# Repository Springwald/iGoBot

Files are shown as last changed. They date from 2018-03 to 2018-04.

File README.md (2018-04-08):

iGoBot - a GO game playing robot

	 _ _____      ______       _   
	(_)  __ \     | ___ \     | |  
	 _| |  \/ ___ | |_/ / ___ | |_ 
	| | | __ / _ \| ___ \/ _ \| __|
	| | |_\ \ (_) | |_/ / (_) | |_ 
	|_|\____/\___/\____/ \___/ \__|
                               
Project website: [http://www.springwald.de/hi/igobot](http://www.springwald.de/hi/igobot)



Licensed under MIT License (MIT)

Copyright (c) 2018 Daniel Springwald | daniel@springwald.de

Permission is hereby granted, free of charge, to any person obtaining a copy of this software and associated documentation files (the "Software"), to deal in the Software without restriction, including without limitation the rights to use, copy, modify, merge, publish, distribute, sublicense, and/or sell copies of the Software, and to permit persons to whom the Software is furnished to do so, subject to the following conditions:

The above copyright notice and this permission notice shall be included in all copies or substantial portions of the Software.

THE SOFTWARE IS PROVIDED "AS IS", WITHOUT WARRANTY OF ANY KIND, EXPRESS OR IMPLIED, INCLUDING BUT NOT LIMITED TO THE WARRANTIES OF MERCHANTABILITY, FITNESS FOR A PARTICULAR PURPOSE AND NONINFRINGEMENT. IN NO EVENT SHALL THE AUTHORS OR COPYRIGHT HOLDERS BE LIABLE FOR ANY CLAIM, DAMAGES OR OTHER LIABILITY, WHETHER IN AN ACTION OF CONTRACT, TORT OR OTHERWISE, ARISING FROM, OUT OF OR IN CONNECTION WITH THE SOFTWARE OR THE USE OR OTHER DEALINGS IN THE SOFTWARE.

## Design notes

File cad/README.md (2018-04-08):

iGoBot - a GO game playing robot

	 _ _____      ______       _   
	(_)  __ \     | ___ \     | |  
	 _| |  \/ ___ | |_/ / ___ | |_ 
	| | | __ / _ \| ___ \/ _ \| __|
	| | |_\ \ (_) | |_/ / (_) | |_ 
	|_|\____/\___/\____/ \___/ \__|
                               
Project website: [http://www.springwald.de/hi/igobot](http://www.springwald.de/hi/igobot)

## CAD Files

### The stone dispenser

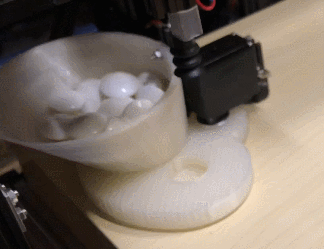
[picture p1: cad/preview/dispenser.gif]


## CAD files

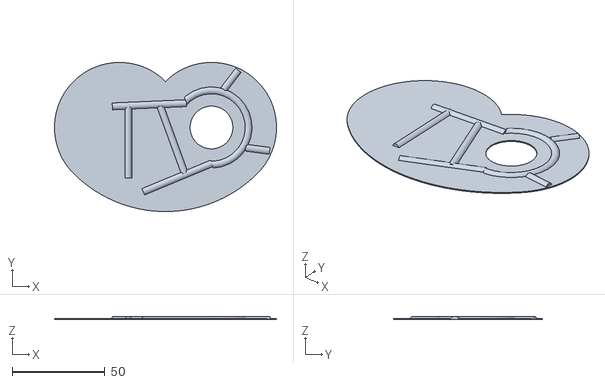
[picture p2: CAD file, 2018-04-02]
cad/StoneDispenserStoneBumper.stl
119.5 x 80.2 x 1.74

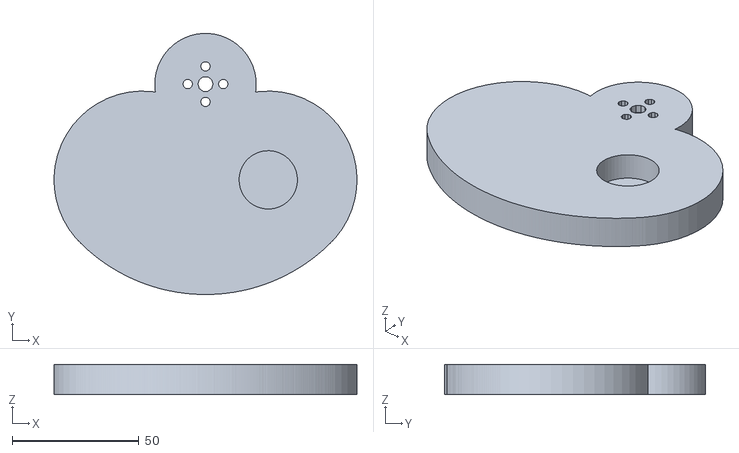
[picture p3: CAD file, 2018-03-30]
cad/StoneDispenserPlate.stl
119.5 x 102.9 x 12.0

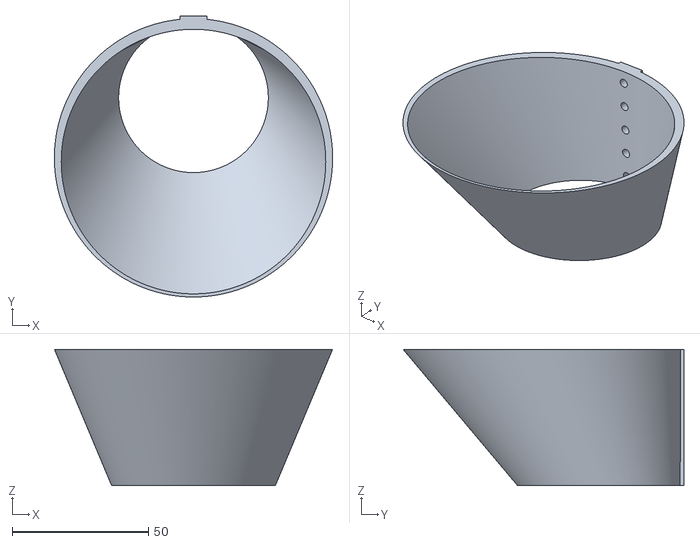
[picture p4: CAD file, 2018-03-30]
cad/StoneDispenserStorage.stl
102.0 x 103.0 x 50.0

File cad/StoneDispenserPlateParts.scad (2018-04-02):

/*
iGoBot - a GO game playing robot
	 _ _____      ______       _   
	(_)  __ \     | ___ \     | |  
	 _| |  \/ ___ | |_/ / ___ | |_ 
	| | | __ / _ \| ___ \/ _ \| __|
	| | |_\ \ (_) | |_/ / (_) | |_ 
	|_|\____/\___/\____/ \___/ \__|
                               
Project website:
http://www.springwald.de/hi/igobot

 #########################
 # stone dispenser plate #
 #########################

 Licensed under MIT License (MIT)

 Copyright (c) 2018 Daniel Springwald | daniel@springwald.de

 Permission is hereby granted, free of charge, to any person obtaining
 a copy of this software and associated documentation files (the
 "Software"), to deal in the Software without restriction, including
 without limitation the rights to use, copy, modify, merge, publish,
 distribute, sublicense, and/or sell copies of the Software, and to permit
 persons to whom the Software is furnished to do so, subject to
 the following conditions:

 The above copyright notice and this permission notice shall be
 included in all copies or substantial portions of the Software.

 THE SOFTWARE IS PROVIDED "AS IS", WITHOUT WARRANTY OF ANY KIND, EXPRESS
 OR IMPLIED, INCLUDING BUT NOT LIMITED TO THE WARRANTIES OF MERCHANTABILITY,
 FITNESS FOR A PARTICULAR PURPOSE AND NONINFRINGEMENT. IN NO EVENT SHALL
 THE AUTHORS OR COPYRIGHT HOLDERS BE LIABLE FOR ANY CLAIM, DAMAGES OR OTHER
 LIABILITY, WHETHER IN AN ACTION OF CONTRACT, TORT OR OTHERWISE, ARISING
 FROM, OUT OF OR IN CONNECTION WITH THE SOFTWARE OR THE USE OR OTHER
 DEALINGS IN THE SOFTWARE.

*/

function resolutionLow() = ($exportQuality==true) ? 30 : 10;
function resolutionHi() = ($exportQuality==true) ? 300 : 50;

storageHeight = 50;
plateWidth= 70;
plateHeight = 12;
storageWidth = plateWidth-10;
servoMove = 13;

module ServoAxisDisc(holeRadiusPlus) {
    discHeight = 2;
    discRadius = 10;
    //translate([0, 0, discHeight/2]) cylinder(h=discHeight, r=discRadius, $fn=resolutionLow(), center=true); 
    
    mountingHoleSpacing = 14.0/2;
    holeHeight=60;
    holeRadius = 1.9+holeRadiusPlus;
    translate([+mountingHoleSpacing,0, 2+holeHeight/2]) cylinder(h=holeHeight, r=holeRadius, $fn=resolutionLow(), center=true); 
    translate([-mountingHoleSpacing,0, 2+holeHeight/2]) cylinder(h=holeHeight, r=holeRadius, $fn=resolutionLow(), center=true); 
    translate([0,+mountingHoleSpacing, 2+holeHeight/2]) cylinder(h=holeHeight, r=holeRadius, $fn=resolutionLow(), center=true); 
    translate([0,-mountingHoleSpacing, 2+holeHeight/2]) cylinder(h=holeHeight, r=holeRadius, $fn=resolutionLow(), center=true); 
    
    // Screw hole middle
    translate([0,0, 2+holeHeight/2])  cylinder(h=holeHeight, r=3+holeRadiusPlus, $fn=resolutionLow(), center=true); 
}

module GoStone() {
    height = 10;
    diameter = 23;
    color([1,0,0]) {
        cylinder(h=height, r=diameter/2, $fn=resolutionHi(), center=true); 
        //cylinder(h=height*10, r=diameter/3, $fn=resolutionHi(), center=true); 
    }
}

module MakerBeamHoles() {
    height  = 40;
    radius = 3.3;
    for(y = [0 : 10: height]) {
        translate([0,30,y+5]) {
            rotate( [0,90,90]) 
            {
                cylinder(h=30, r=radius/2, $fn=resolutionLow(), center=true); // base body corner
            }
        }
    }
}

module StorageShape(height, radius, widthAddScale, margin) {
    linear_extrude(height, center = true, convexity = 100, scale=widthAddScale + margin/radius) 
        translate([0, -radius-margin, 0])
            circle(r=radius, $fn=resolutionHi());
}

module Storage3() {
    widthAddScale = 1.7;
    margin = 3;
    difference() 
    {
        color([0.7,0.7,1]) 
        {
         translate([0, storageWidth/2 , storageHeight / 2]) 
            difference() {
                StorageShape(storageHeight, storageWidth/2, widthAddScale, 0);
                radiusMinusElement = (storageWidth-margin*2)/2;
                translate([0, margin/2 ,0]) 
                    StorageShape(storageHeight+2,radiusMinusElement , widthAddScale , margin);
            }
         translate([0,storageWidth/2,storageHeight/2]) cube([10,2,storageHeight], center=true);
        }
     MakerBeamHoles();
    }
}

module PlateRaw(height){
    difference() 
    {
        union()
        {
            for (i = [-45:45]) {
                rotate([0,0,i]) {
                    translate([0,-plateWidth/2,-plateHeight/2]) cylinder(h=height, r=plateWidth/2, $fn=resolutionHi(), center=true); 
                }
            }
        }
        union() {
           rotate([0,0,45]) {
            translate([0,-plateWidth/2,-4.9])  GoStone();
           }
        }
    }
}

module PlateStoneBumper() {
    height = 0.5;
    bumperHeight = 2;
    
    
    difference()  {
        
        union() {
        
            translate([0,0,-0.5]) PlateRaw(height);
            
            // ring
            difference() {
                rotate([0,0,45]) 
                    translate([0,-plateWidth/2,-15-bumperHeight]) 
                        rotate_extrude(convexity = 10,  $fn=resolutionLow())
                            translate([20, 10, 0])
                                circle(r = bumperHeight,  $fn=resolutionLow());
                translate([0,-plateWidth/3,0]) 
                    rotate([0,0,45/2]) 
                        cube([30,100,30], center=true);
            }
            
            //line1+2
            translate([0,-plateWidth/2-1,-5-bumperHeight]) 
                rotate([0,0,45/2]) {
                    translate([1,25,0])
                        rotate([90,0,70]) 
                            cylinder(h=40, r=bumperHeight, $fn=resolutionLow(), center=true); 
                    translate([0,-17,0])
                        rotate([90,0,90]) 
                            cylinder(h=40, r=bumperHeight, $fn=resolutionLow(), center=true); 
                }
           
            // line 3
            translate([4,-12,-5-bumperHeight]) 
                translate([0,-20,0])
                    rotate([90,0,20]) 
                        cylinder(h=40, r=bumperHeight, $fn=resolutionLow(), center=true); 
            
            //line4+5
            translate([42,-18,-5-bumperHeight]) 
                rotate([0,0,45/2]) {
                    translate([1,20,0])
                        rotate([90,0,120]) 
                            cylinder(h=13, r=bumperHeight, $fn=resolutionLow(), center=true); 
                    translate([0,-20,0])
                        rotate([90,0,60]) 
                            cylinder(h=13, r=bumperHeight, $fn=resolutionLow(), center=true); 
                }
                
            // line 6
            translate([-20,-12,-5-bumperHeight]) 
                translate([0,-20,0])
                    rotate([90,0,0]) 
                        cylinder(h=40, r=bumperHeight, $fn=resolutionLow(), center=true); 
        }
        translate([0,0,-16.75]) cube([400,400,20],center=true);
    }
}

module Plate(rotation) {
    
    // The servo holder
    difference() 
    {
        translate([0,servoMove,-plateHeight/2]) 
        {
            cylinder(h=plateHeight, r=20, $fn=resolutionHi(), center=true); 
        }
        union() {
            rotate([0,180,0]) translate([0,servoMove,-10]) ServoAxisDisc(holeRadiusPlus=0);
            rotate([0,0,0]) translate([0,servoMove,-65]) ServoAxisDisc(holeRadiusPlus=3);
        }
    }

    // The plate
    PlateRaw(plateHeight);

    
}



//$exportQuality = false;
color([0,1,0]) cylinder(h=200, r=1, $fn=resolutionLow(), center=true); 

//translate([0,0,1]) Storage3(); 


translate([0,plateWidth/2,0]) {
    rotate([0,0,0]) {
        //Plate();
    }
}

PlateStoneBumper();

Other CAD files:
cad/StoneDispenserPlate.scad
cad/StoneDispenserStoneBumper.scad
cad/StoneDispenserStorage.scad

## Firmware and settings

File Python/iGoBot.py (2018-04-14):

#!/usr/bin/python
#-*-coding:utf-8-*-
#vim: set enc=utf8:

#     iGoBot - a GO game playing robot
#      _ _____      ______       _   
#     (_)  __ \     | ___ \     | |  
#      _| |  \/ ___ | |_/ / ___ | |_ 
#     | | | __ / _ \| ___ \/ _ \| __|
#     | | |_\ \ (_) | |_/ / (_) | |_ 
#     |_|\____/\___/\____/ \___/ \__|
#                              
#     Project website: http://www.springwald.de/hi/igobot
#
#     Licensed under MIT License (MIT)
#
#     Copyright (c) 2018 Daniel Springwald | daniel@springwald.de
#
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
import os, sys
from os.path import abspath

import time
from random import randrange, uniform
import math
import pygame
import grovepi
import random

from Board import Board
from GnuGoRemote import GnuGoRemote
from CameraStoneDetection import CameraStoneDetection
from BoardDetectionCalibration import BoardDetectionCalibration
from DanielsRasPiPythonLibs.speech.SpeechOutput import SpeechOutput

from DanielsRasPiPythonLibs.hardware.PCF8574 import PCF8574
from DanielsRasPiPythonLibs.hardware.I2cIoExpanderPcf8574Synchron import I2cIoExpanderPcf8574Synchron
from DanielsRasPiPythonLibs.hardware.RgbLeds import RgbLeds
from hardware.Light import Light
from hardware.Motors import Motors
from hardware.iGoBotRgbLeds import iGoBotRgbLeds

import atexit
import gettext

englishSpeech = False

if (englishSpeech == True):
	en = gettext.translation('iGoBot', localedir='locale', languages=['en'])
	en.install
	_ = en.gettext
else:
	_ = lambda s: s

class iGoBot:

	englishSpeech 					= True;

	I2cIoExpanderPcf8574Adress		= 0x3e

	_lightGrovePort					= 8
	_soundcard						="plughw:1"
	
	_ended							= False
	_released						= False
	
	_motors							= None;
	_light							= None;
	_leds							= None;
	_speech							= None;
	_board							= None;
	_switches 						= None;
	
	_gnuGo							= None;
	
	_camera							= None;
	_cameraStoneDetection			= None;
	
	
	def __init__(self, boardSize=13):
		#pygame.init()
		#pygame.mixer.quit() # to prevent conflicts with speech output (audio device busy)
		#screenInfo = pygame.display.Info()
		#if (screenInfo.current_w > 900):
		#self.lcd = pygame.display.set_mode((800,480))
		#else:
		#	self.lcd = pygame.display.set_mode((800,480), FULLSCREEN, 16)
		
		self._light = Light(self._lightGrovePort);
		self._light.On();
		
		self._leds = iGoBotRgbLeds();
		
		if (englishSpeech==True):
			self._speech = SpeechOutput(soundcard=self._soundcard, voice="-ven");
		else:
			self._speech = SpeechOutput(soundcard=self._soundcard, voice="-vmb-de2");
			
		
		
		self._board = Board(boardSize);
		
		self._switches = I2cIoExpanderPcf8574Synchron(self.I2cIoExpanderPcf8574Adress, useAsInputs=True)
		
		self._motors = Motors(self._switches);
		
		self._motors.MoveOutOfCameraSight();
		
		self._camera = CameraStoneDetection();

		self._gnuGo = GnuGoRemote(boardSize=boardSize)
		
		# move to stone storage drop
		if (False):
			self._motors.DropStoneInStorage();
			time.sleep(30);
		
		# test stone board coordinates
		if (False):
			#for i in [[0,0],[0,12],[12,12],[12,0]]:
			for i in [[0,0],[0,8],[8,8],[8,0]]:
				self._motors.MoveToXY(self._board.GetStepperXPos(i[0]),self._board.GetStepperYPos(i[1]));
				for a in range(0,3):
					self._motors.TakeStoneFromBoard();
					self._motors.PutStoneToBoard();
					time.sleep(1);
		
		# take stone from 0, 0 and drop it into storage
		if (False):
			self._motors.MoveToXY(self._board.GetStepperXPos(0), self._board.GetStepperYPos(0));
			self._motors.TakeStoneFromBoard();
			self._motors.DropStoneInStorage();
			
		self._motors.MoveOutOfCameraSight();
		
		# calibrate camera with 4 black and 1 white stones
		self._cameraStoneDetection = BoardDetectionCalibration(self._camera, boardSize);
		while(self._cameraStoneDetection.IsCalibrated()==False):
			self._cameraStoneDetection.Calibrate();
		return;

	def RemoveCapturedStoneFromBoard(self,x ,y):
		stepperX = self._board.GetStepperXPos(x);
		stepperY = self._board.GetStepperYPos(y);
		self._motors.MoveToXY(stepperX, stepperY);
		# take stone
		self._motors.TakeStoneFromBoard();
		# drop left or right from board
		if (self._board.GetField(x,y)== Board.Empty):
			self.Speak(_("Fehler! Ich wollte den Stein auf {x}/{y} entfernen, aber dort ist laut meiner Aufzeichnung gar kein Stein.").format(x=x,y=y));
			return;
		self._motors.DropCapturedStone(self._board.GetField(x,y) == Board.Black);
		self._board.SetField(x,y,Board.Empty);

	def PutStoneToFieldPos(self, fieldX, fieldY):
		stepperX = self._board.GetStepperXPos(fieldX);
		stepperY = self._board.GetStepperYPos(fieldY);
		self._motors.MoveToXY(stepperX, stepperY);
		self._motors.PutStoneToBoard();
		
	def UpdateFace(self):
		if (self._speech.IsSpeaking()):
			self._leds.Speak();
		else:
			self._leds.NeutralFace();
		
	def Speak(self, sentence, wait=False):
		print(">>>>>>" ,sentence);
		self._speech.Speak(sentence, wait=False);
		if (wait):
			while(self._speech.IsSpeaking()):
				self.UpdateFace();
				self._motors.UpdateMotors();
				self._motors.UpdateGripperAndDispenser();
				time.sleep(0.25);
			self.UpdateFace();

	def StoreAllWhiteStones(self):
		tries = 0;
		while (tries < 5):
			tries = tries + 1;
			
			# move arm out of camera sight
			self._motors.MoveOutOfCameraSight();
		
			# check camera detection of white stones
			self._motors.UpdateMotors();
			self._cameraStoneDetection.Update();
			whiteStones = self._cameraStoneDetection.WhiteStones
			if (len(whiteStones) > 0):
				# there are still white stones
				tries = 0;
				# move to first white stone
				stone = whiteStones[0];
				print("found white stone on {field}".format(field=self._cameraStoneDetection.FieldToAZNotation(stone[0],stone[1])));
				stepperX = self._board.GetStepperXPos(stone[0]);
				stepperY = self._board.GetStepperYPos(stone[1]);
				self._motors.MoveToXY(stepperX, stepperY);
				# take white stone
				self._motors.TakeStoneFromBoard();
				# drop stone into storage
				self._motors.DropStoneInStorage();
			else:
				# no more white stones
				print("no white stone detected, try {tries}".format(tries=tries));
				self._motors.UpdateMotors();
				time.sleep(1);
			
	def WaitTillButtonPressed(self, color="green"):
		pressed = False;
		self._motors.StandByAllMotors();
		# wait till pressed
		while(pressed == False):
			self._motors.UpdateGripperAndDispenser;
			self._leds.AnimateButtonGreen();
			self._leds.NeutralAndBlink();
			if (self._switches.getBit(bit=16)):
				pressed = True;
			self.UpdateFace();
		# wait till released
		while(pressed == True):
			self._motors.UpdateGripperAndDispenser;
			self._leds.AnimateButtonGreen();
			if (not self._switches.getBit(bit=16)):
				pressed = False;
		self.UpdateFace();
		self._leds.ClearButton();
		self._motors.WakeUpAllMotors();

	def GetNewStones(self, color=Board.Black):
		self._motors.MoveOutOfCameraSight();
		for i in range(1,2):
			self._cameraStoneDetection.Update();
		if (color==Board.Black):
			stones = self._cameraStoneDetection.BlackStones;
		else:
			stones = self._cameraStoneDetection.WhiteStones;
		newStones = self._board.GetNewStones(stones, color);
		return newStones;

	def ClearBoard(self):
		self._gnuGo.ClearBoard();
		self._board = Board(self._board._boardSize);
		
	def FindBestCameraSettings(self, ignoreStones=[]): # ignoreStones are xy of stones, we don´t know, if they are really on the board. Like the last robot set stone.
		# find out the camera setting where all stones on the board are detected correct
		return;

	def RemoveCapturesStonesFromBoard(self):
		removed = Board.RemovedStones(self._board, self._gnuGo.GetActualBoard());
		if (len(removed) > 0):
			self.Speak(_("Ich nehme nun {count} Steine vom Brett").format(count=len(removed)), wait=False);
			for stone in removed:
				self.RemoveCapturedStoneFromBoard(stone[0],stone[1]);

	def PlayAiStone(self,white=True):
		field = self._gnuGo.AiPlayWhite();
		self.UpdateFace();
		if (field==None):
			print("Error: gnuGo AI suggested no white stone?!?");
			return False;
		if (field=="PASS"):
			self.Speak(_("Ich passe!"), wait=False);
			return True;
		xyPos = self._board.AzToXy(field);
		print ("white AI stone to:", xyPos);
		successfulDropped = False;

		self.FindBestCameraSettings();

		while(successfulDropped == False):

			bot._motors.GrabStoneFromStorage();
			bot.PutStoneToFieldPos(xyPos[0],xyPos[1]);
			
			newStoneDetectionSuccessfull = False;
			while(newStoneDetectionSuccessfull == False):
				
				# check if stone really reached board
				newWhiteStones = self.GetNewStones(color=Board.White);
				if (len(newWhiteStones)==1):
					if (newWhiteStones[0] == xyPos):
						successfulDropped = True;
						newStoneDetectionSuccessfull = True;
					else:
						self.Speak(_("Oh, ich habe einen anderen neuen Stein, als den von mir gesetzten, erkannt."));
						self.Speak(_("Ich versuche, meine Kamera neu einzustellen."));
						self.Speak(_("Einen Augenblick bitte"), wait=False);
						self.FindBestCameraSettings(ignoreStones=[xyPos]);
						newStoneDetectionSuccessfull = False;
				else:
					if (len(newWhiteStones)==0):
						# set stone ist missing
						self.Speak(_("Oh, ich konnte wohl keinen Stein greifen. Bitte prüfe, dass mein Vorrat  nicht leer ist"));
						self.Speak(_("Ich versuche es noch einmal"), wait=False);
						# recalibreate y-axis
						self._motors.MoveToY(500);
						self._motors._yAxis.calibrateHome();
						newStoneDetectionSuccessfull = True;
					else:
						# more than 1 new stone detectec. re-set camera
						self.Speak(_("Oh, ich erkenne {count} neue weiße Steine.").format(count=len(newWhiteStones)));
						self.Speak(_("Ich versuche, meine Kamera neu einzustellen."));
						self.Speak(_("Einen Augenblick bitte"), wait=False);
						self.FindBestCameraSettings(ignoreStones=[xyPos]);
						newStoneDetectionSuccessfull = False;

		self._board.SetField(xyPos[0],xyPos[1],Board.White);
		return True;

	def PlayWhiteGame(self):
		self.ClearBoard();
		
		self.Speak(_("Bitte lege Deine schwarzen Vorgabe Steine auf das Brett. Drücke dann die Taste."), wait=False);
		self.WaitTillButtonPressed(color="green");
		
		# detect handycap stones
		self._motors.UpdateMotors();
		self._motors.UpdateGripperAndDispenser();
		handicapStones = self.GetNewStones(color=Board.Black);

		if (len(handicapStones) == 0):
			self.Speak(_("Du hast keine Vorgabe Steine gelegt."), wait=False);
			whiteToPlay = False;
		else:
			self.Speak(_("Du hast {count} Vorgabe Steine gelegt.").format(count=len(handicapStones)), wait=False);
			for stone in handicapStones:
				self._board.SetField(stone[0],stone[1],Board.Black);
				fieldAz = self._board.XyToAz(stone[0],stone[1]);
				print ("check set black: {field}".format(field=self._board.GetField(stone[0],stone[1])));
				self._gnuGo.PlayerPlayBlack(fieldAz);
			whiteToPlay = True;

		roundNo = 0;

		while(True):

			if (whiteToPlay):
				if (roundNo < 3):
					self.Speak(_("Ich bin am Zug. Bitte einen Augenblick Geduld."), wait=False);
					self.UpdateFace();
				if (self.PlayAiStone(white=True))==True:
					self.UpdateFace();
					whiteToPlay = False;
					roundNo = roundNo+1;
			else:
				self._motors.MoveOutOfCameraSight();
				self.Speak(_("Du bist am Zug."), wait=False);
				if (roundNo < 3):
					self.Speak(_("Bitte lege einen schwarzen Stein und drücke dann die Taste."), wait=False);
				self.FindBestCameraSettings();
				self.WaitTillButtonPressed(color="green");
				newBlackStones = self.GetNewStones(color=Board.Black);
				if (len(newBlackStones) == 0):
					self.Speak(_("Ich sehe keinen neuen schwarzen Stein"), wait=False);
				else:
					if (len(newBlackStones) == 1):
						for stone in newBlackStones:
							self._board.SetField(stone[0],stone[1],Board.Black);
							fieldAz = self._board.XyToAz(stone[0],stone[1]);
							self._gnuGo.PlayerPlayBlack(fieldAz);
							
							rnd = random.randrange(30);
							if (rnd==1):
								self.Speak(_("Ein interessanter Zug."),wait=False);
							elif (rnd==2):
								self.Speak(_("Wow, darauf wäre ich nicht gekommen."),wait=False);
							elif (rnd==3):
								self.Speak(_("Ok, das ist also Dein Zug."),wait=False);
							whiteToPlay = True;
							roundNo = roundNo+1;
					else:
						self.Speak(_("Ich sehe {count} statt einem neuen schwarzen Stein").format(count=len(newBlackStones)), wait=False);
						
			self.RemoveCapturesStonesFromBoard();

	def Release(self):
		if (self._released == False):
			self._released = True
			print ("shutting down iGoBot")
			
			if (self._cameraStoneDetection != None):
				self._cameraStoneDetection.Release();
				
			if (self._camera != None):
				self._camera.Release();

			if (self._light != None):
				self._light.Off();
				self._light.Release();
				
			if (self._leds != None):
				self._leds.Release();
				
			if (self._speech != None):
				self._speech.Release();
				
			if (self._motors != None):
				self._motors.Release()

			if (self._gnuGo != None):
				self._gnuGo.Release();

			self._ended = True

	def __del__(self):
		self.Release()
		

		
def exit_handler():
	bot.Release()

if __name__ == "__main__":
	
	bot = iGoBot(boardSize=9)
	
	if (False):
		bot.Speak(_("Hallo"))
		bot.Speak(_("Möchtest Du eine Partie go mit mir spielen?"));
		bot.Speak(_("Ich habe eine Spielstärke von etwa 5 kyu."))
	
	atexit.register(exit_handler)

	bot.PlayWhiteGame();
	
	#bot.StoreAllWhiteStones();
	
	if (False):	
		for i in range(0,9):
			bot._motors.GrabStoneFromStorage();
			bot._motors.PutStoneToFieldPos(i,i);


        
        
        
        

    

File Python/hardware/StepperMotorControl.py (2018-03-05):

#!/usr/bin/env python

#     #########################################
#     # abstract stepper motor control module #
#     #########################################
#
#     Licensed under MIT License (MIT)
#
#     Copyright (c) 2018 Daniel Springwald | daniel@springwald.de
#
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
import time
from GroveI2CMotorDriver import GroveI2CMotorDriver
from I2cIoExpanderPcf8574 import I2cIoExpanderPcf8574
from MultiProcessing import *
from SharedInts import SharedInts
from SharedFloats import SharedFloats



class StepperMotorControl(MultiProcessing):

	_motorName						= "untitled"

	__shared_ints__						= None
	__target_pos_int__					= 0
	__calibrating__int__				= 0
	__actual_pos__int__					= 0 # 0=endstop pos, StepsProRound=360°
	__actual_step_data_pos_int__		= 0
	__last_step_data_pos_int__			= 0
	
	__shared_floats__					= SharedFloats(max_length=1)
	__last_step_data_pos_change_float__	= __shared_floats__.get_next_key()

	MaxSteps						= 1600      # how many motor steps can the motor maximum move 

	_isClosedCircle					= True      # is 0 to maxSteps a full round to the same endstop

	_fastestSpeedDelay				= 0.002     # how fast can the stepper motor go
	_slowestSpeedDelay				= _fastestSpeedDelay * 2 
	_calibrateSpeedDelay			= _fastestSpeedDelay * 5 
	_actualSpeedDelay				= _slowestSpeedDelay

	_rampSpeedup					= 1.05      # how fast is the speed of for motor ramping
	_rampDistance					= 0         # how many steps before the target pos start to ramp down (calculated automatically)
	_rampSafeArea					= 35        # prevent to come nearer than this to the endstop

	_stepData						= []  # the stepper motor step bits

	_releasedMotor					= False

	def __init__(self):
		print ("init " + self._motorName + " speed:" + str(self._fastestSpeedDelay ) + " slowest:" + str(self._slowestSpeedDelay))

		self._processName = self._motorName
		super().__init__(prio=-20)
		
		self.__shared_ints__					= SharedInts(max_length=5)
		self.__target_pos_int__					= self.__shared_ints__.get_next_key()
		self.__calibrating__int__				= self.__shared_ints__.get_next_key()
		self.__actual_pos__int__				= self.__shared_ints__.get_next_key() # 0=endstop pos, StepsProRound=360°
		self.__actual_step_data_pos_int__		= self.__shared_ints__.get_next_key()
		self.__last_step_data_pos_int__			= self.__shared_ints__.get_next_key()
		
		self.actualPos = 0
		self.targetPos = 0
		self.actualStepDataPos = 0
		self.lastStepDataPos = -1
		self.lastStepDataPosChange = 0

	
	def start(self):
		self.calibrating = False
		self.calibrateHome()
		self._calculateRampDistance();
		super().StartUpdating()

	def _endStop(self): # True: endstop is reached
		raise Exception("not implemented!")

	def _updateMotorSteps(self): # write motor data to steps
		raise Exception("not implemented!")
		
	## multi process properties START ##
	
	@property
	def targetPos(self):
		return self.__shared_ints__.get_value(self.__target_pos_int__)
	@targetPos.setter
	def targetPos(self, targetPos):
		#print (self.__targetPosKey)
		targetPos = int(min(self.MaxSteps - self._rampSafeArea, targetPos))
		targetPos = int(max(self._rampSafeArea, targetPos))
		self.__shared_ints__.set_value(self.__target_pos_int__, targetPos)

	@property
	def actualPos(self):
		return self.__shared_ints__.get_value(self.__actual_pos__int__)
	@actualPos.setter
	def actualPos(self, pos):
		self.__shared_ints__.set_value(self.__actual_pos__int__, pos)

	@property
	def calibrating(self):
		return self.__shared_ints__.get_value(self.__calibrating__int__) == 1
	@calibrating.setter
	def calibrating(self, value):
		if (value == True):
			self.__shared_ints__.set_value(self.__calibrating__int__, 1)
		else:
			self.__shared_ints__.set_value(self.__calibrating__int__, 0)

	@property
	def lastStepDataPos(self):
		return self.__shared_ints__.get_value(self.__last_step_data_pos_int__)
	@lastStepDataPos.setter
	def lastStepDataPos(self, value):
		self.__shared_ints__.set_value(self.__last_step_data_pos_int__, value)

	@property
	def lastStepDataPosChange(self):
		return self.__shared_floats__.get_value(self.__last_step_data_pos_change_float__)
	@lastStepDataPosChange.setter
	def lastStepDataPosChange(self, value):
		self.__shared_floats__.set_value(self.__last_step_data_pos_change_float__, value)

	@property
	def actualStepDataPos(self):
		return self.__shared_ints__.get_value(self.__actual_step_data_pos_int__)
	@actualStepDataPos.setter
	def actualStepDataPos(self, value):
		self.__shared_ints__.set_value(self.__actual_step_data_pos_int__, value)

	@property
	def targetReached(self):
		return int(self.actualPos) == int(self.targetPos)

	## multi process properties END ##

	def Update(self):
		if (self.calibrating == True): 
			time.sleep(1)
			#print ("NOT! updating " + self._motorName)
			return

		#print ("updating " + self._motorName + " :" + str(self.GetActualPos()))
		# Check if unexpected end top contact
		if (self._endStop()):
			print ("oha - the endstop of motor " + self._motorName + " is reached this should not happen when running normal")
			# oha - the endstop is reached this should not happen when running normal
			if (self.actualPos > self.MaxSteps / 2):
				# is over the half round -> drive back half a round
				for i in range(1, int(self.MaxSteps / 2)):
					self._stepBackwards()
					self._updateMotorSteps()
			#else:
				# is under the half round -> calibrate normal
			self.calibrateHome()

		# check if have to move to target
		timeSinceLastUpdate = time.time() - self.lastStepDataPosChange
		if (timeSinceLastUpdate < self._actualSpeedDelay):
			time.sleep((self._actualSpeedDelay - timeSinceLastUpdate)/2)
        
		# check if stepper update can be done
		if (self.targetReached==True):
			self._actualSpeedDelay = self._slowestSpeedDelay
		else:
			distance = self.targetPos - self.actualPos
			if (abs(distance) < self._rampDistance): # getting slow when near to target
				# is near to target 
				if (self._actualSpeedDelay < self._slowestSpeedDelay):
					self._actualSpeedDelay = min(self._slowestSpeedDelay, self._actualSpeedDelay * self._rampSpeedup)
			else:
				# far away from target
				if (self._actualSpeedDelay > self._fastestSpeedDelay):
					self._actualSpeedDelay= max(self._fastestSpeedDelay, self._actualSpeedDelay / self._rampSpeedup)
				
			if (int(distance) > 0):
				self._stepForward()
				self._updateMotorSteps()
			else:
				if (int(distance) < 0):
					self._stepBackwards()
					self._updateMotorSteps()
				else:
					time.sleep(0.5)
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

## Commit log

2018-03-06 working on y stepper motor control
2018-03-21 all axis and gripper working
2018-03-22 tuning motor speeds
2018-03-22 all motors in one code file, first working stone gripper test
2018-03-23 changed board resolution to 13x13
2018-03-27 working on camera detection
2018-03-28 camera stone detection and preview
2018-03-28 calibration detects 5 stones
2018-03-28 optimizing board calibration detection
2018-03-29 faster camera performance
2018-03-30 added GO stone dispenser CAD files
    [StoneDispenserPlate.scad, StoneDispenserPlate.stl, StoneDispenserPlateParts.scad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]
2018-03-31 better board stepper position calibration
2018-04-01 better calibrating storage grabber
2018-04-02 added stone bumper to dispenser plate
    [StoneDispenserPlateParts.scad, StoneDispenserStoneBumper.scad, StoneDispenserStoneBumper.stl]
2018-04-02 power off for servos implemented
2018-04-02 speech and button integration
2018-04-04 better stepper positions and ai gameplay
2018-04-04 init relais for servo control
2018-04-05 addes 9x9 board; first playing test working
2018-04-05 adjustable camera settings
2018-04-06 removed camera test
2018-04-06 syncing speech and face led
2018-04-07 better board converting and comparing
2018-04-08 moved motors to seperate lib
2018-04-08 bugfixes on board coordinates
    [Board.py, GnuGoRemote.py, Motors.py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]
